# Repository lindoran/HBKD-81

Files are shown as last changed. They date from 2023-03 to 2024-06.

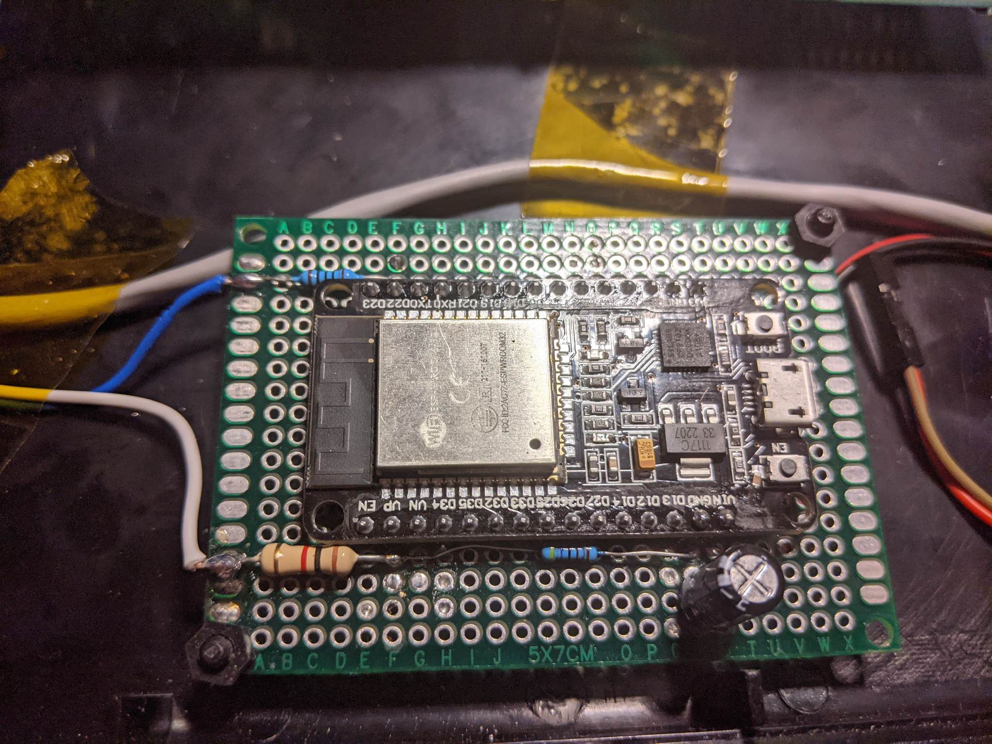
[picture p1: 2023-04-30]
Pictures/ZXWespi Zoomed in (minimal install).jpg

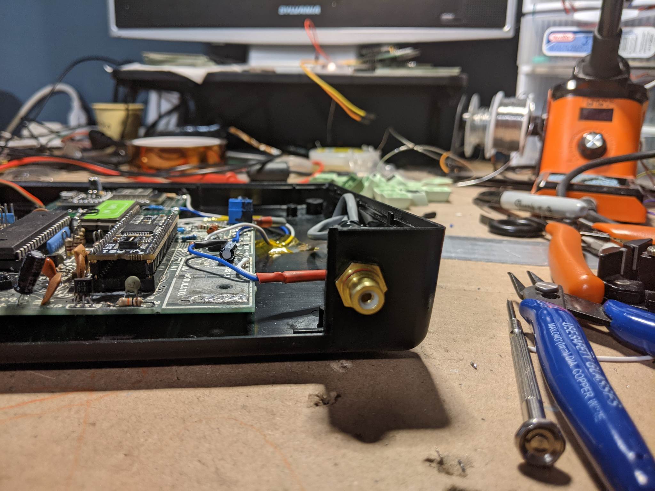
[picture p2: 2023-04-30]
Pictures/video port.jpg

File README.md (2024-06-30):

# HBKD-81
A Open hardware, ZX81 keyboard and case design, based off modern availible parts.

Here is the design info with some Caveats: 
 - This is CERN-OHL-P - see the very easy to understand open hardware license 
 - I don't make any grantees or warrantees; see the legal disclaimers below
 - I don't intednd to sell a product here just sharing what I have, that being 
   said.  I am an amature, there may be mistakes but my boards worked right
   out of the box.  additionally i do have experience in home brew and hobby computers
   electronics (formal trade school training) and I try to test everything out.
 - <strike>No BOM as of yet, but that hopefully completed by the end of the week.  some
   details of what I ordered so far are on the hack a day.  (actually updating the 
   repo on my lunch break at work!)</strike>
 - BOM is updated and in Gerber's directory  
    - UPDATE: looks like the BOM, while complete is insufficient to use with most PCB assembly services working on a solution but for now it seems self assembly is the only option 
 - 3D .STL files for the test fit pannel is avalible and verified to work.
 - 2D CAD files for all the case pannels (top and back) availble, please read the build guide in that space.
 - designs are all copyright David Collins 2023

<B>UPDATE:</B>

 Thanks to Dr Matt Regan for trying out the keyboard on his ZX Spectrum 48k clone. I have updated some 
 errors in the silk screen and added notes to the keyboard showing both types of connections.

IMAGE ALT TEXT HERE (https://www.youtube.com/watch?v=If8GkpuakHM)

Sponsorship: 
  
  This prototype was sponsored by PCBWay!  see their website here for Fabrication, PCB Manufacture 
  and more!
  
  http://www.pcbway.com

Hack a day site:
  For project updates please check the hack a day here:
  
  https://hackaday.io/project/189795-hbkd-81
 
 You can contact me at Z80dad (at) gmail (dot) com
 
 Section 5 of the license: 
 
 5 DISCLAIMER AND LIABILITY

  5.1 DISCLAIMER OF WARRANTY -- The Covered Source and any Products
      are provided 'as is' and any express or implied warranties,
      including, but not limited to, implied warranties of
      merchantability, of satisfactory quality, non-infringement of
      third party rights, and fitness for a particular purpose or use
      are disclaimed in respect of any Source or Product to the
      maximum extent permitted by law. The Licensor makes no
      representation that any Source or Product does not or will not
      infringe any patent, copyright, trade secret or other
      proprietary right. The entire risk as to the use, quality, and
      performance of any Source or Product shall be with You and not
      the Licensor. This disclaimer of warranty is an essential part
      of this Licence and a condition for the grant of any rights
      granted under this Licence.

  5.2 EXCLUSION AND LIMITATION OF LIABILITY -- The Licensor shall, to
      the maximum extent permitted by law, have no liability for
      direct, indirect, special, incidental, consequential, exemplary,
      punitive or other damages of any character including, without
      limitation, procurement of substitute goods or services, loss of
      use, data or profits, or business interruption, however caused
      and on any theory of contract, warranty, tort (including
      negligence), product liability or otherwise, arising in any way
      in relation to the Covered Source, modified Covered Source
      and/or the Making or Conveyance of a Product, even if advised of
      the possibility of such damages, and You shall hold the
      Licensor(s) free and harmless from any liability, costs,
      damages, fees and expenses, including claims by third parties,
      in relation to such use.

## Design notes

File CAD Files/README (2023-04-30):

These are the cad files:

A few details, The 2d cad files do not specify thickness.  
The PT-10 Drawings state .062" thick aluminum.  If you are 
doing the top panel, a 2MM (.072") panel was used in the 
prototype (as that's the actual depth of the cavity.) A 1.6mm 
panel is going to be weaker and there will be a lip at the 
edge of the cavity.

the back panel is actually a lot closer to .062".  If you 
get ambitious and combine the two panels on the same sheet, 
you are going to run into problems making the back panel fit 
at 2MM.  I made it work but its very tight fit.   If you 
wind up customizing the panel with cut outs its going to 
crack if you try to force it with any amount of structural cut 
outs.  For the back panel I recommend using 1.57 to 1.6mm 
thick material. I pulled all of the factory installed Tinnerman 
Fasteners off the case, they got in the way. You can use them 
with machine screws but I just ended up using m3 size screws 
everywhere.

if you just order the case without panels (I recommend this, 
you aren't using them) It won't come with them installed (or
shouldn't). The PT-10 drawings specify this as part 61691-02.

I used a standard kit of nylon m3 stand offs and screws off of 
amazon. I didn't keep track of the sizing.  I used a threaded post 
stand off and nuts to hold the PCB to the top panel with a screw, 
but there's loads of configurations depending on the height you'd 
like the keys to be from the top of the panned. Mine sit fairly low.

the PCB is just mounted to the bottom of the case with the same 
nylon standoffs. I put screws through the bottom into threaded 
stand offs and held the pcb to the tops with nuts. you can do
what you feel comfortable with there.

A BIG POINTER: use round panel mounts everywhere you can. 
unless you are very good with a Dremmel its going to be 
drastically easier to get the holes in, just start with a small
bit and step up the size.  I would go with point to point
wiring here. so much of the design relies on analog concepts,
you don't want to introduce noise into an otherwise noisy design 
adding a whole other PCB is going to add complexity.

I put a copy of the PT-10 drawings in the documents folder if 
somebody needs dimensions for some other reason.

The case can be found on mouser here: https://mou.sr/3LkjQmr  
Mouser #:616-82404-501-000  | MFR:82404-501-000 PT-10 BLACK 

I believe there's also a listing on digikey. 

case costs about 17.00 US

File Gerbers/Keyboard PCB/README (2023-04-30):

UPDATE the BOM is complete but insufficient for use with most PCB assembly services working on a solution but for the time being self assembly is currently the only option for the keyboard PCB.

See the CAD files space for directions on asembling the case.

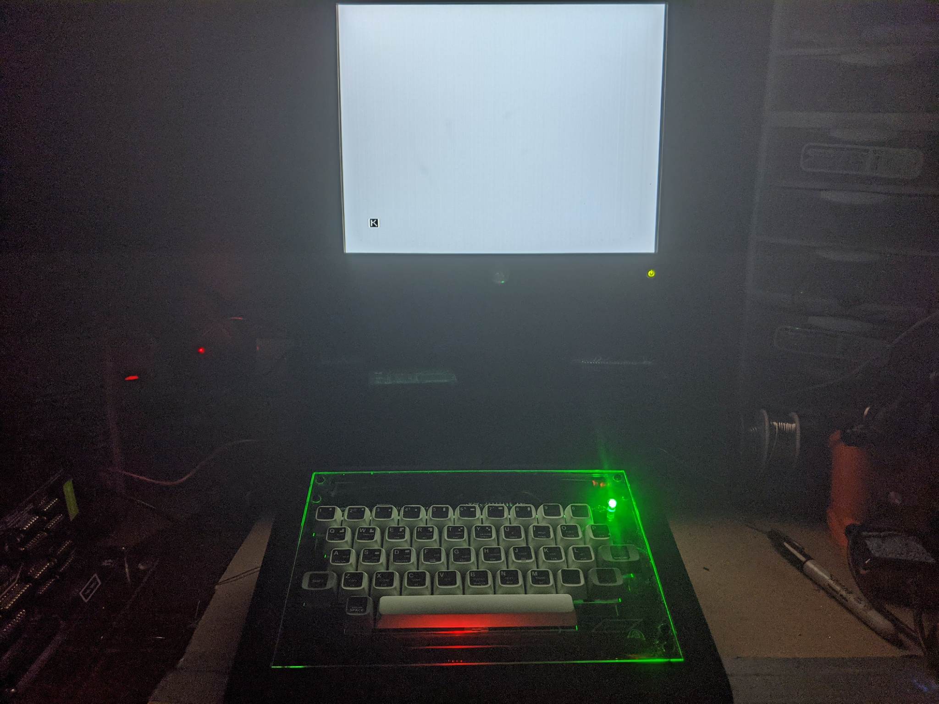
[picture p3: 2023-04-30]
Pictures/low light workspace shot.jpg

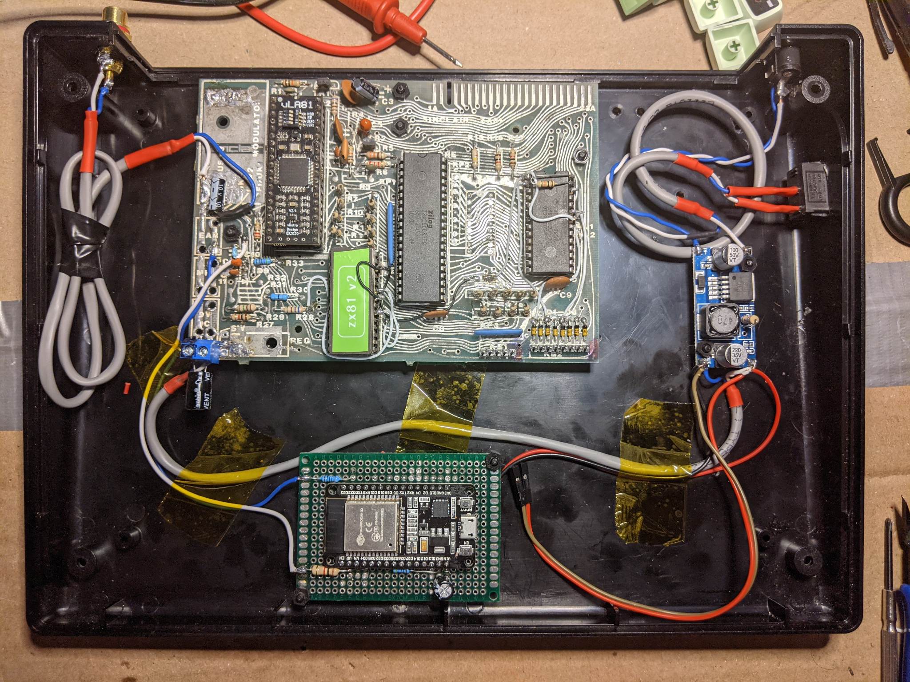
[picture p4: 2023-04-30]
Pictures/top down interal (full).jpg

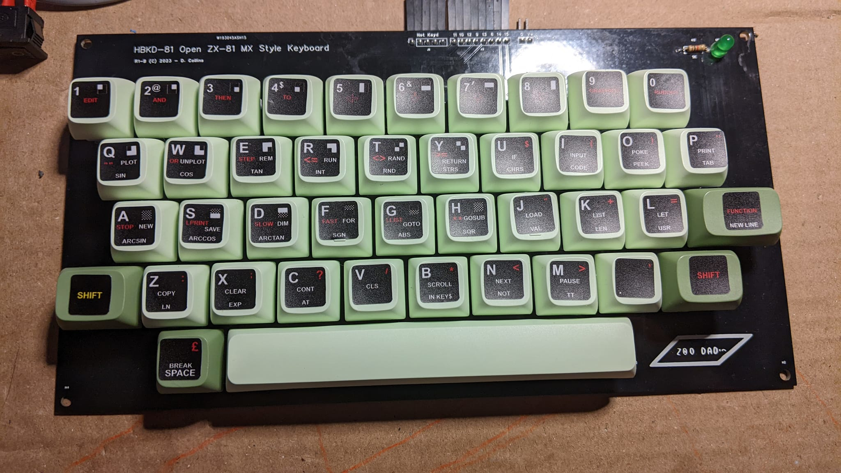
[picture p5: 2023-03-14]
Pictures/Prototype with stickers.png

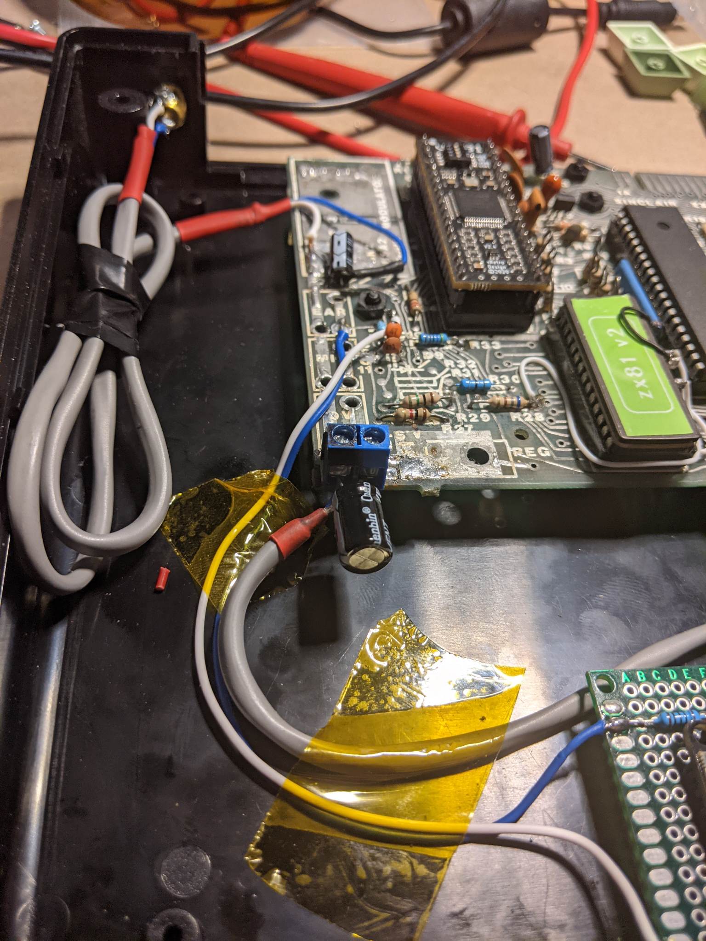
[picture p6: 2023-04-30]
Pictures/ripple reduction hack.jpg

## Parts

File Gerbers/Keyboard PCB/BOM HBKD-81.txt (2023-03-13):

HBKD-81 BOM

.--------.-------------.------.---------------------------.---------------------.-------------------------------.---------------------.-----------.-----------------------------------------------------.
| Item # | *Designator | *Qty |       Manufacturer        |     *Mfg Part #     |      Description / Value      | *Package/Footprint  |   Type    |              Your Instructions / Notes              |
:--------+-------------+------+---------------------------+---------------------+-------------------------------+---------------------+-----------+-----------------------------------------------------:
|      1 | K0 – K41    |   42 | Cherry                    | MX1A-11NW           | SWITCH PUSH SPST-NO 0.01A 12V | 2POS                | Thru-hole | This is the bulk cherry MX part see notes*          |
:--------+-------------+------+---------------------------+---------------------+-------------------------------+---------------------+-----------+-----------------------------------------------------:
|      2 | U2          |    1 | Stackpole Electronics Inc | CFM14JT1K00         | 1K ¼ Watt Resister 5%         | 2POS                | Thru-hole | any tolerance 1K ohm Res that fits in the footprint |
:--------+-------------+------+---------------------------+---------------------+-------------------------------+---------------------+-----------+-----------------------------------------------------:
|      3 | U1          |    1 | Cree LED                  | C503C-RCS-CYAZaAA2  | RED LED T – 1 ¾               | 2POS                | Thru-hole | any 5mm led 1.5-2v (should be slightly dim)         |
:--------+-------------+------+---------------------------+---------------------+-------------------------------+---------------------+-----------+-----------------------------------------------------:
|      4 | J1          |    1 | NorComp                   | 27630502RP2         | 1x5 Header pins rt. Angle     | 5POS                | Thru-hole | Any 1x5 header for dupont                           |
:--------+-------------+------+---------------------------+---------------------+-------------------------------+---------------------+-----------+-----------------------------------------------------:
|      5 | J3          |    1 | Harwin                    | M20-9750846         | 1x8 Header pins rt. Angle     | 8POS                | Thru-hole | any 1x8 header for dupont                           |
:--------+-------------+------+---------------------------+---------------------+-------------------------------+---------------------+-----------+-----------------------------------------------------:
|      6 | H5          |    1 | TE Connectivity           | 826949-2            | 1x2 Header pins rt. Angle     | 2POS                | Thru-hole | any 1x2 header for dupont                           |
'--------'-------------'------'---------------------------'---------------------'-------------------------------'---------------------'-----------'-----------------------------------------------------'

*Cherry MX switches can be substituted for any available compatible footprint with the plastic PCB mount lugs, check your switches to make sure they are not panel mount.

**You will also need a 6.25 Sized PCB Mount “snap in” stabilizer, this one from Amazon was used in the prototype: https://www.amazon.com/Genuine-Cherry-PCB-Snap-Stabilizers/dp/B085T8QZJC

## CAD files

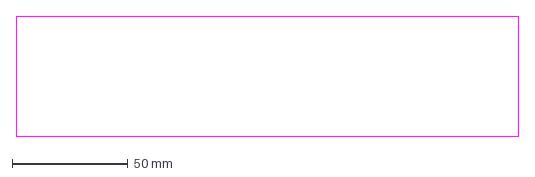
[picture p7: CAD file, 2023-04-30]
CAD Files/HBKD-81 Back Pannel_2023-04-06.dxf
217.3 x 52.3 mm

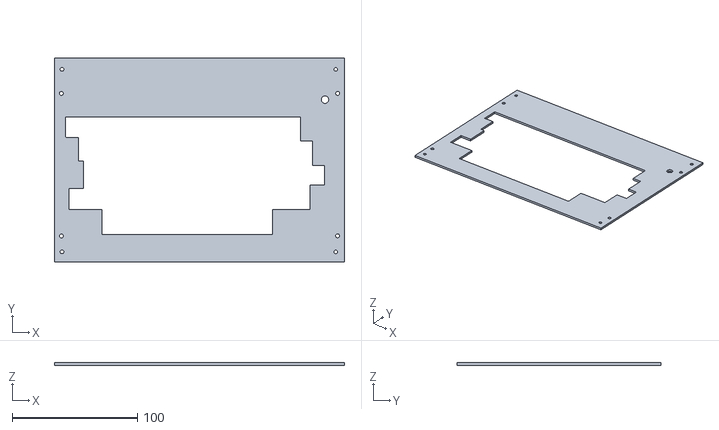
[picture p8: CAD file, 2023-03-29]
CAD Files/HBKD-81 Top Pannel for PT-10.stl
232.0 x 163.0 x 2.00

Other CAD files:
CAD Files/HBKD-81 Top Pannel for PT-10.dxf

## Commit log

2023-03-09 Initial Commit
    rough commit so community members can start pcb manufacture for the keyboard.
2023-03-09 2nd Try initial commit
    Making the gerbers available so people can get process going for manufacture
2023-03-13 updated BOM
    BOM updated
    [BOM HBKD-81.csv, BOM HBKD-81.xlsx]
2023-03-29 Add cad files for top pannel (3d Print)
    [HBKD-81 Top Pannel for PT-10.stl]
2023-04-30 add 2D Cad files for PT-10 case
    This is just adds the 2d drawings for case inserts
    [HBKD-81 Back Pannel_2023-04-06.dxf, HBKD-81 Top Pannel for PT-10.dxf]
2023-04-30 Update README
    Update build instructions for case.
2024-06-16 Updated Silkscreen
    Pin out silkscreen was incorrect. Thanks for Matt Regan's video reminding me to update this
